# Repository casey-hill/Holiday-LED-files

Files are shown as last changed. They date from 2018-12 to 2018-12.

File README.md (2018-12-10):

# Holiday LED

Here's my guide to building the Holiday LED lights. This guide is designed to help those who haven't been using Home Assistant in the past or for those who are trying to understand where things are broken. I'm also going to provide some key tips to avoid some extra work.

I have enough experience with Arduino and Smartthings; I figured this wouldn't be too hard but found most guides are out of date and it was a challenge to troubleshoot.

Why recreate what other's have done? I found many guides out there but struggled to understand how to programtically identify what my problems where. I hope this guide will help those wehre I struggled.

## Summary:

 I followed [DrZzs guide](https://www.youtube.com/watch?v=6Y6jUM1OaYM&t=1s) which motivied me to create this guide but also used [Ben's videos too](https://www.youtube.com/watch?v=9KI36GTgwuQ). Ben's are great to get up and running and DrZze's guide helped me understand more about the LEDs.

## Hardware (Home Assistant) ~$60

* https://www.amazon.com/gp/product/B01CD5VC92/ref=oh_aui_detailpage_o05_s00?ie=UTF8&psc=1
* https://www.amazon.com/gp/product/B011RBJUOC/ref=oh_aui_detailpage_o05_s01?ie=UTF8&psc=1
* https://www.amazon.com/gp/product/B00MARDJZ4/ref=oh_aui_detailpage_o05_s02?ie=UTF8&psc=1
* https://www.amazon.com/gp/product/B06XX29S9Q/ref=oh_aui_detailpage_o05_s02?ie=UTF8&psc=1

## Software ~$free

* [Arduino 1.8.7](https://www.arduino.cc/en/Main/Software)
* [Download the Hass.io image for your device]( https://github.com/home-assistant/hassos/releases/download/1.13/hassos_rpi3-1.13.img.gz)
* [Download Etcher to write the image to an SD card]( https://www.balena.io/etcher/)

## Lights

* [LED 2811](https://www.amazon.com/gp/product/B01AU6UG5C/ref=oh_aui_detailpage_o04_s03?ie=UTF8&psc=1)
* [Soderless Board]( https://www.amazon.com/gp/product/B0727X6N9D/ref=oh_aui_detailpage_o04_s00?ie=UTF8&psc=1)
* [D1 board](https://www.amazon.com/gp/product/B01N3P763C/ref=oh_aui_detailpage_o04_s00?ie=UTF8&psc=1)
* [2nd 8266 board](https://www.amazon.com/gp/product/B010O1G1ES/ref=oh_aui_detailpage_o01_s00?ie=UTF8&psc=1)
* [Sealed box](https://www.amazon.com/gp/product/B005T990I0/ref=oh_aui_detailpage_o03_s00?ie=UTF8&psc=1)
* [Wire](https://www.amazon.com/gp/product/B0119IE4C6/ref=oh_aui_detailpage_o03_s00?ie=UTF8&psc=1)
* [PowerSupply](https://www.amazon.com/gp/product/B06XK3X3PW/ref=od_aui_detailpages00?ie=UTF8&psc=1)
* [J-Channel](https://www.homedepot.com/p/Metal-Sales-2-in-x-10-5-ft-J-Channel-Drip-Edge-Flashing-in-White-4227430/204256712)

## Optional

These are things I used or found helpful during my installation. I wanted to make my board more modualar and also overcome some challenges.
* [PBC board](https://www.amazon.com/gp/product/B01N3161JP/ref=oh_aui_detailpage_o03_s00?ie=UTF8&psc=1)
* [Male/Female pins](https://www.amazon.com/gp/product/B074HVBTZ4/ref=oh_aui_detailpage_o03_s00?ie=UTF8&psc=1)
* [Male/Female connectors](https://www.amazon.com/gp/product/B00NBSH4CA/ref=oh_aui_detailpage_o04_s01?ie=UTF8&psc=1)
* [Logic Shifter](https://www.amazon.com/gp/product/B0148BLZGE/ref=oh_aui_detailpage_o04_s02?ie=UTF8&psc=1)

## Tools
* Sodering iron + sodder
* Drill
* 1/2 drill bit
* philips screw driver
* saw horse
* two childern
* ladder
* 3D printer
* wire strippers
* screws

## Overall process

* Home assistant OS install
* Home assistant configuration
* Home assisant configure MQTT
* Home assistant add the lights
* Uploading the Arduino Code
* Installing the hardware

### Home assitant OS install

I had actually no problems following the setup guides mentioned online. DrZzes tells you to follow Ben's video which I linked above. However things have changed since Ben's video. If you follow his guide completely, you'll end up running into trouble.
Follow [Ben's video](https://www.youtube.com/watch?v=9KI36GTgwuQ) to install the home assistant OS on the card, place the card in the Pi and power it up. I'm going to assume you can figure out how to connect at this point, you should assign it a static ip address and connect via ip address as opposed to the the name of the Pi.

Now, it is imporant to undestand, Ben provides a lot of good tips in the entire video so please watch it all. I'll call out his tips on: checking the configuration file and restarting the server. I would ignore the MQTT installation and Samba installation sections as they are not necessary for this setup.

### Home assitant Configuration

Configuration of Home Assistant Walk through the setup questions. Once you are logged in, you will want to install the web based editor. Ben described how to do this above, so this is one step you will follow. That is it, you don't need to install or add anything additional. MQTT broker is already installed on this version of the Hass.io.

**TIP** - Edit your configuraiton.yaml file. Add one line to the end of the file (later you'll be asked for the username which is in the documentatation; homeassistant); you don't need to put in a ip address or port number as others have mentioned

MQTT
 
    password: makeoneyoucanremember

At this point, do a configuration file check and reboot the server.

Once the Home Assistant is up and running, check the log file to verify there are no issues.

### Home Assistant MQTT Configuration

As I mentioned above, all you need to do is add MQTT at the end of the configuration.yaml file and add the password. Don't specifiy the username as it is already preconfigured as homeassistant.

### Home Assistant adding the lights

Up to this point, you have installed Home Assistant and enabled the use of MQTT with a password of your choice. It's now time to configure Home Assistant to how the light switch, theme and animation speeds.

Doing this is super simple, just navigate to the end of the configuration.yaml file and past in the particial Configuration.yaml file that DrZzs provided.

Now check the configuration file and reboot the server.

Once the server is up and running, you should see the new buttons added.

### Updating the Arduino code

Generally speaking, there were minor changes here for this to work.  I would state you need to follow Ben's video to import the libraries.  I know during the time I was using the arduino code, I saw errors with one of the libraries but I just commented it out.  

The other pain I had was the chip DrZzs uses would not work on D4, only until I changed it to just 5 did I see things working.  

### Installing the hardware

This area was a little lacking in the videos and I had to make a few decisions.  

#### PowerSupply

*First*

you going to need a powercord to plug-in to the power supply.  If you don't know which one is "N" vs "L", you should!  Here is the easy way to tell, I looked at my cord to determine which one the larger (the two prongs), traced the wire to the end and use this diagram.  

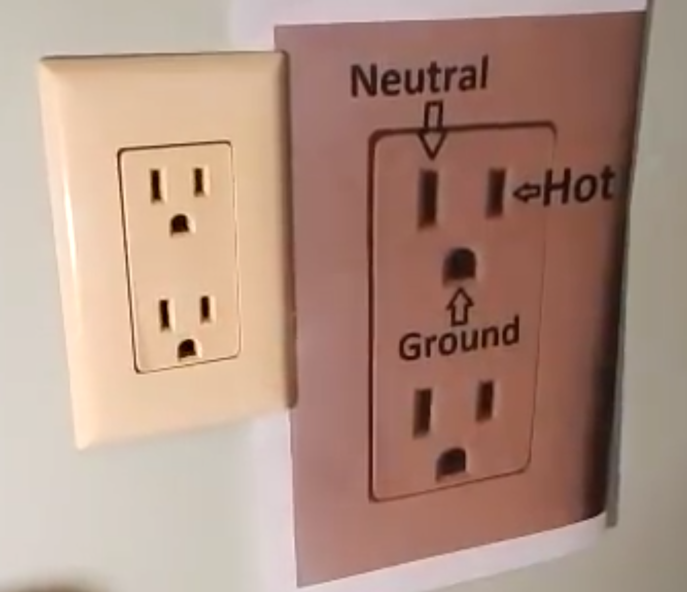
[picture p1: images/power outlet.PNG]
120v wiring
 

*Second*

I would strongly recommend using a breadboard at this point.  If things don't work, you'll want to rewire and there is no better way than a breadboard.

Wire up the breadboard using this diagram; again I'm not using the D1 board because I didn't want to have the issues with distance using the data pin.  I also didn't get a chance to try out D1 using the logic shifter due to time.

Use the wiring diagram as shown.

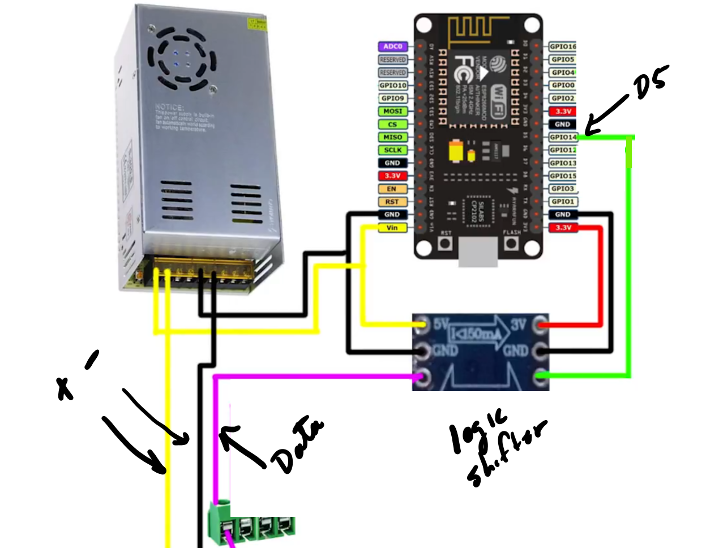
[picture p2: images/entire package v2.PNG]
5v wiring


**STOP**
Before you do anything else, you should try turning off the lights/on and changing the themes. At this point, I plugged in everything and just made sure it all worked.   

*Third*

Short version, I installed the j-channel with the lights to the roof, plugged in the arduino to verify everything was working.  After the mounting, I went back and installed the power/data cables.  Finally completed everything by mounting the box and the electronics in the box.

J-Channel needs to be drilled every 3 inches using the template; you can print it yourself or make your own with wood or metal.  The holes are 3 inches; I started my holes 1.5" from the end.

This is where the 2 teenagers can help out.  This is a time consuming process and takes about 10 minutes for each 12' J-Channel.
J-Channel

You might recall, the female end of the lights must be the end you start with.  The data line starts there and repeats the signal.  If you install the lights in the J-Channel wrong, don't worry, you can pull them all out and start over like I did.

Generally, speaking, the gutters held the j-channel in place and I didn't have to scren them to the soffet.

I also made a 3D part [part one](https://github.com/casey-hill/Holiday-LED-files/blob/master/stl/J-Channel%20Cap%20with%20hole.stl) to cap off the J-Channel; one has a hole for wires while the other has no holes at all.

### Additional Pictures

**FAQ** 

**Q.** Why are the first 10 or so lights turning on but the rest of the string is off?

**A.** If you didn't use a power supply, you'll need to purchase the above. If you have the power supply connected, then the code you have on the Arduino is not properly configured or you are using the wrong pin.  Also, the D1 chip doesn't push a full 5 volts which is why only a few work and then it fades out quickly.

**Q.**  My switches are not showing up on Home Assistant

**A.**  Did you install the 3rd party MQTT add-in? I would suggest removing it and using the built-in broker.

**Q.** I noticed after I restarted my server that there are errors. 

**A.** Click on the error and review the error in the configuration.yaml file. Likely the problem will exist there since nothing else is changing.

**Q** Do I need to use the additional logic shifter?

**A**  You don't need to BUT if you are going to jump across spaces in the roof line, then you need one.  There doesn't appear to be limitation on lenght for a roof anyway.  I've jumped 15 feet and 10 feet with no problems.

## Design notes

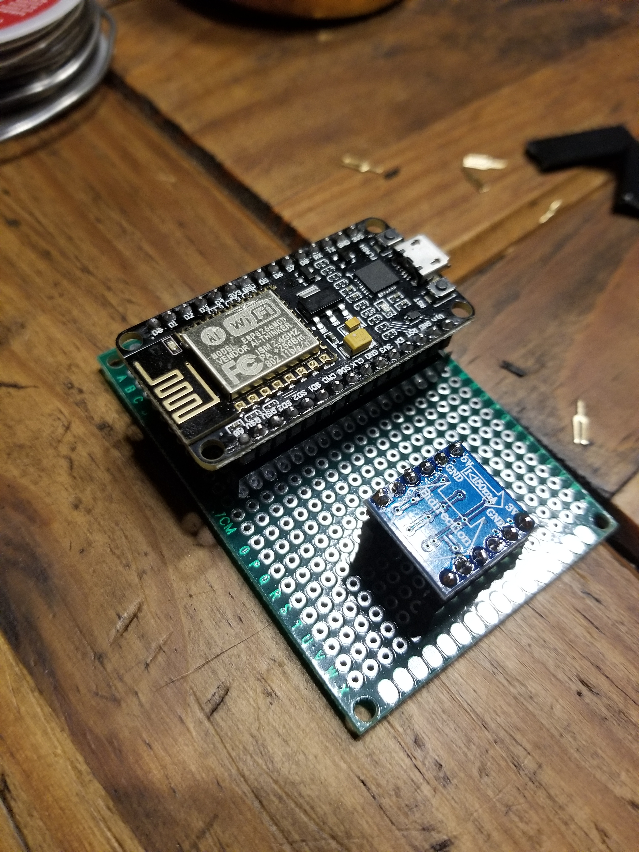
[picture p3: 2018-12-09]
images/board3.jpg

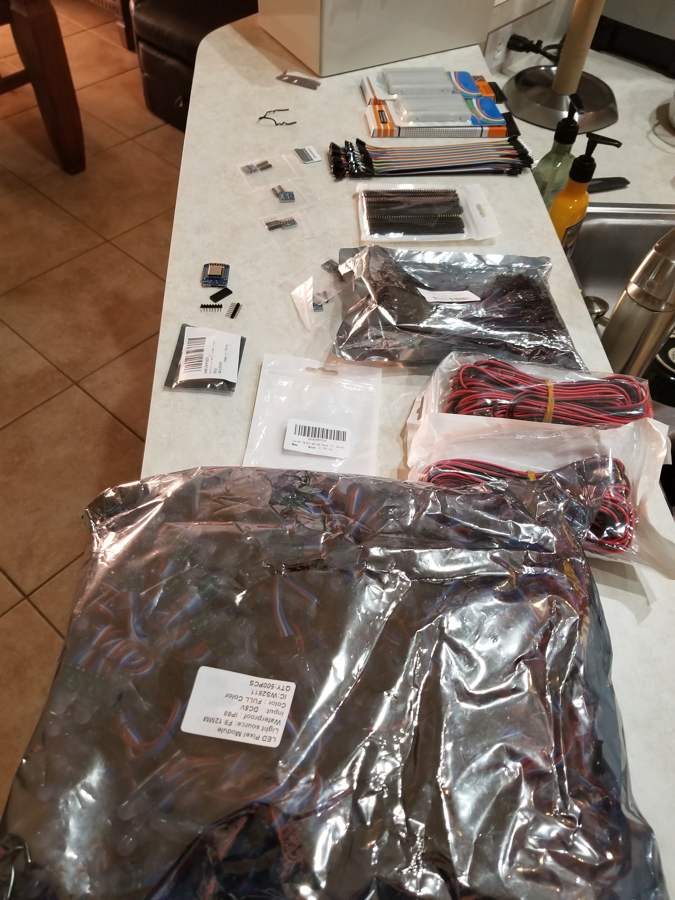
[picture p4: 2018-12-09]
images/misc1.jpg

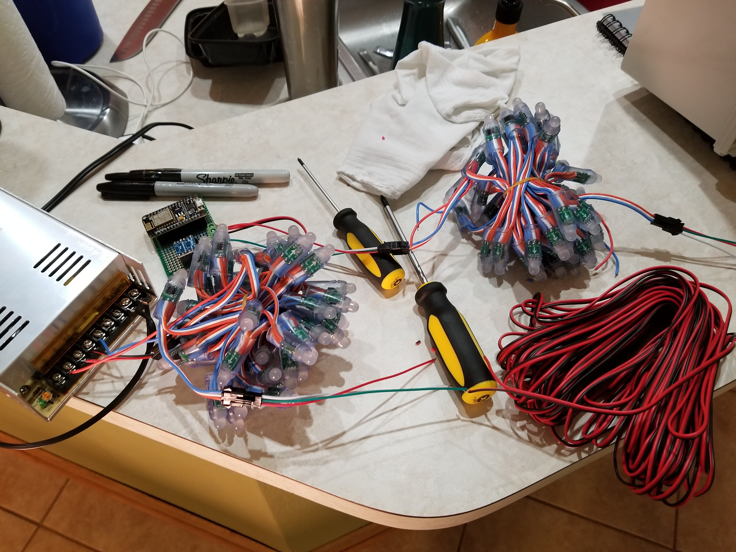
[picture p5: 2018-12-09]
images/misc2.jpg

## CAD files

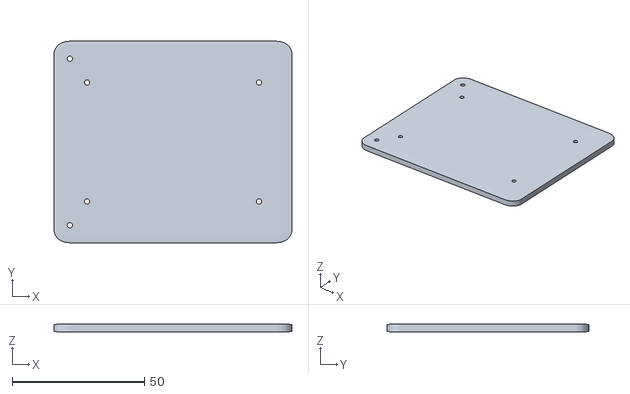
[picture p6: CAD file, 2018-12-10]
stl/PCB Mount.stl
90.0 x 76.2 x 3.00

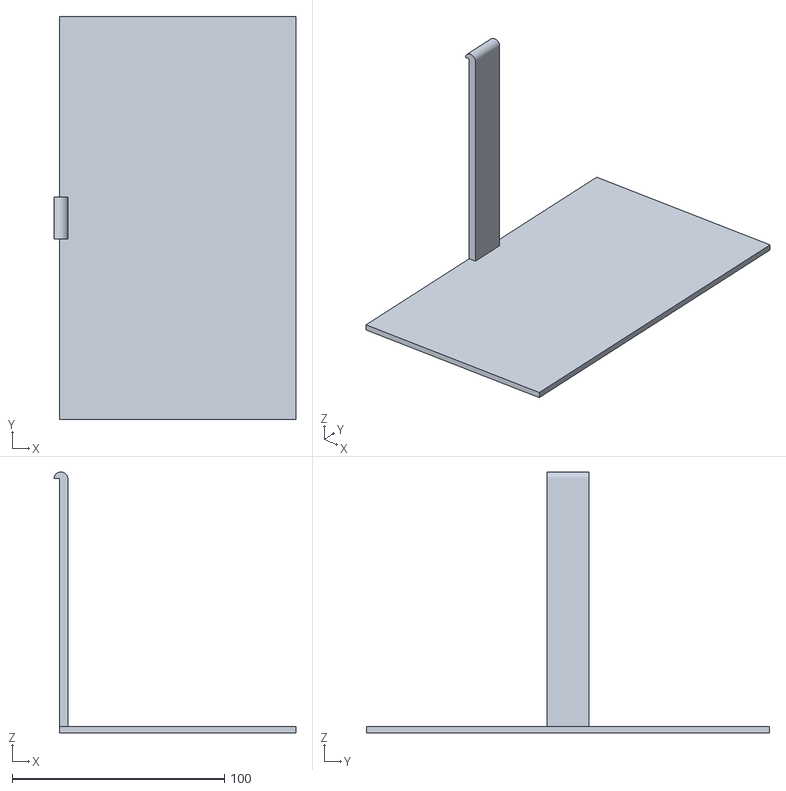
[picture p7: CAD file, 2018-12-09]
stl/Power and Sealed Box mount.stl
114.0 x 190.0 x 123.0

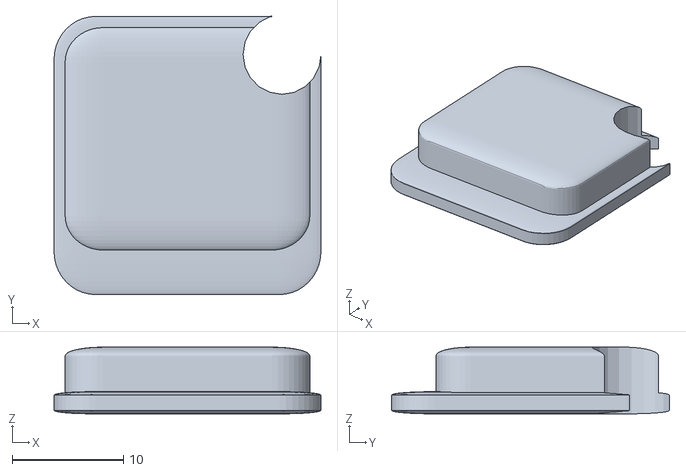
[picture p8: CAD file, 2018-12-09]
stl/J-Channel Cap with hole.stl
24.0 x 25.0 x 6.00

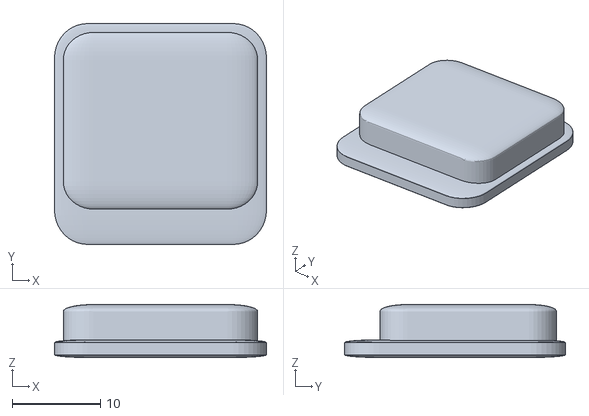
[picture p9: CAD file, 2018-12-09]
stl/J-Channel Cap.stl
24.0 x 25.0 x 6.00
